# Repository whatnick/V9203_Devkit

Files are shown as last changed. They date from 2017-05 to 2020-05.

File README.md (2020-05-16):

# V9203 FeatherWing Devkit
An evaluation board for Vangotech V9203 3-phase energy monitor in a
Featherwing format. It has been tested with Arduino enabled feathers
and should work with any Arduino platform with an SPI bus.

The SPI bus is 3.3v and exposed via the Feather headers and the JST
connector on the top for people wishing to use it with non-feather
format boards as host processor.

The board can be obtained on:

- [Tindie](https://www.tindie.com/products/whatnick/v9203-featherwing/)
- [OSHPark](https://oshpark.com/shared_projects/62lfzmN7)
- [Aisler](https://aisler.net/p/OBAOETDS)
- [PCBWay](https://www.pcbway.com/project/shareproject/V9203_Devkit_Featherwing.html)
  
## Board Images

### Rendered

**Top Render**

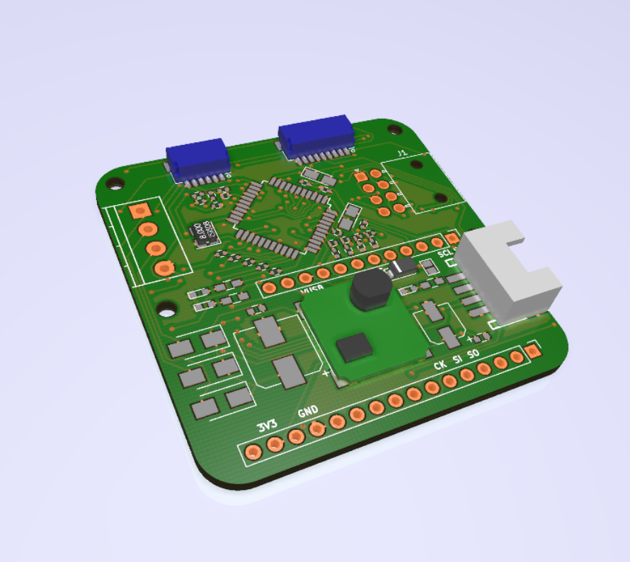
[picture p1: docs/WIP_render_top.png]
Top Render


**Bottom Render**

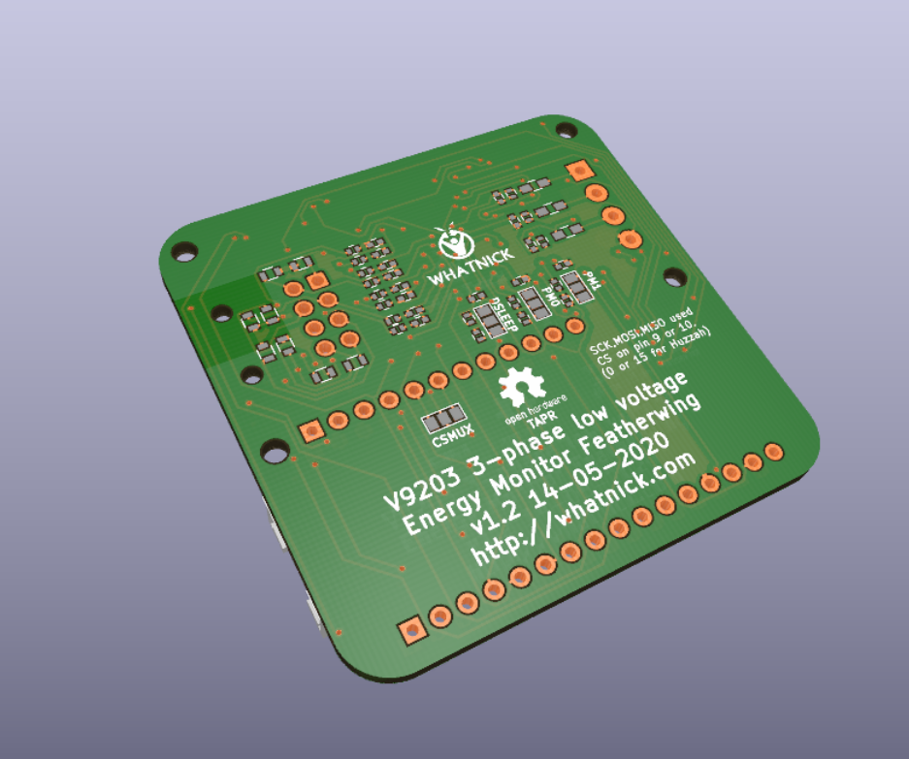
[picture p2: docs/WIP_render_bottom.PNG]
Bottom Render


### Assembled (with RJ45)

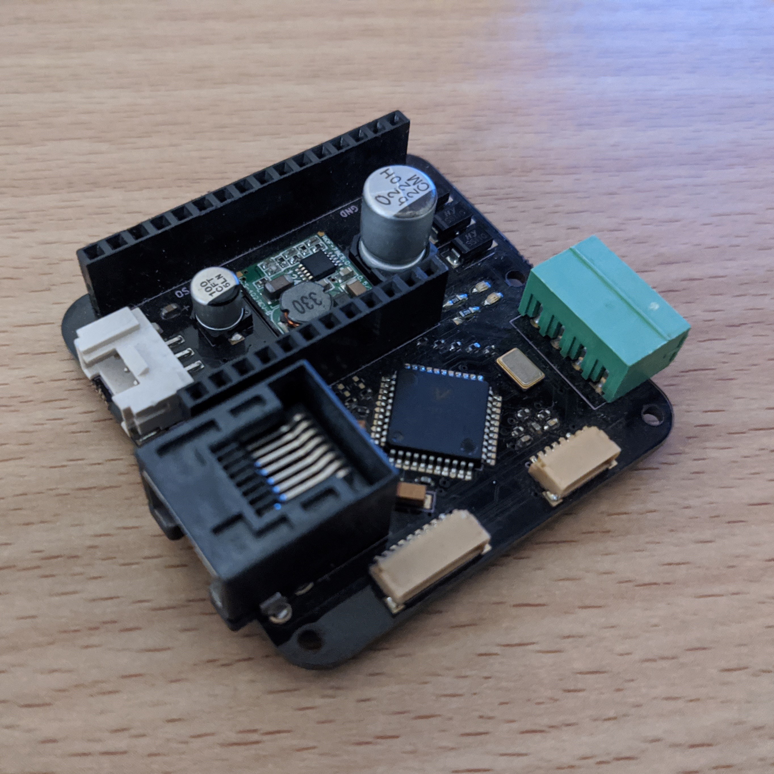
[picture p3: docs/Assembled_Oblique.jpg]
Assembled Oblique


## Arduino Firmware
Arduino Firmware if available in [GitHub](https://github.com/whatnick/V9203_Arduino).

## Micropython Firmware
WIP

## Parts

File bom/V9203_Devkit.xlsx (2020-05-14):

References | manf# | Value | Footprint | Quantity
C23, C24, C25, C26 | 04025C102KAT2A | 1n | C_0402 | 4
C16, C20, C27 | 04026D105KAT2A | 1u | C_0402 | 3
C22 | 0402YC103KAT2A | 10n | C_0402 | 1
C3 | 0603YD105KAT2A | 1u/16V | C_0603 | 1
C5, C6, C7, C8, C9, C10, C11, C12, C15, C17, C18, C19, C21, C28, C29, C30 | C0402C104K4PAC | 100n | C_0402 | 16
C2 | EEEFT1C101AR | 100u/16V | CP_Elec_5x5.8 | 1
C13, C14 | T491A106K016AT | 10u | CP_Tantalum_Case-A_EIA-3216-18_Reflow | 2
C1 | UCM1H221MNL1GS | 220u/50V | CP_Elec_8x10 | 1
C4 | UMK107BJ105KA-T | 1u/50V | C_0603 | 1
R26 | CPF0402B43KE | 43K | R_0402 | 1
R25 | CPF0402B75KE1 | 75K | R_0402 | 1
R6 | CR0402-FX-1000GLF | 100R | R_0402 | 1
R42, R43, R44 | CRCW0402100KFKED | 100K | R_0402 | 3
R33 | CRCW040210K0FKED | 10K | R_0402 | 1
R29, R30, R31, R32 | CRCW04021K00FKED | 1K | R_0402 | 4
R34, R35, R36, R37, R38, R39, R40, R41 | CRCW040220K0FKED | 20K | R_0402 | 8
R1, R27, R28 | CRG0603F1K0 | 1K | R_0603_HandSoldering | 3
R17, R18, R19, R20, R21, R22, R23, R24 | ERJ3BQF2R4V | 2.4R/10ppm | R_0603 | 8
R10, R11, R12 | RG1608P-104-B | 100K | R_0603_HandSoldering | 3
R2, R3, R4, R5, R7, R8, R9, R13, R14, R15, R16 | RT0402FRE07100RL | 100R | R_0402 | 11
D4, D6, D7 | LTST-C190KRKT | LED | LED_0603 | 3
D5 | PMEG2010ER | D_Schottky | D_SOD-123 | 1
D1, D2, D3 | SS110 | D_Schottky | D_SMA_Standard | 3
U2 | ROF-78E5.0-0.5SMD | ROF-78E | SMD-4 | 1
U1 | V9203 | V9203 | TQFP-44_10x10mm_Pitch0.8mm | 1
Y1 | FA-238V 13.0000MB-K0 | Crystal_GND24 | Crystal_SMD_Abracon_ABM8G-4pin_3.2x2.5mm | 1
J1 | 105314-1108 | Conn_01x08 | Molex_Nano-Fit_105314-xx08_2x04_P2.50mm_Horizontal | 1
J4 | 691322110004 | Screw_Terminal_1x04 | TerminalBlock_Pheonix_PT-3.5mm_4pol | 1
J9 | SM06B-SRSS-TB(LF)(SN) | JST6 | JST_SH_SM06B-SRSS-TB_06x1.00mm_Angled | 1
J6 | SM09B-SRSS-TB(LF)(SN) | JST9 | JST_SH_SM09B-SRSS-TB_09x1.00mm_Angled | 1

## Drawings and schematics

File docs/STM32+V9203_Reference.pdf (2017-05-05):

U2

DF04

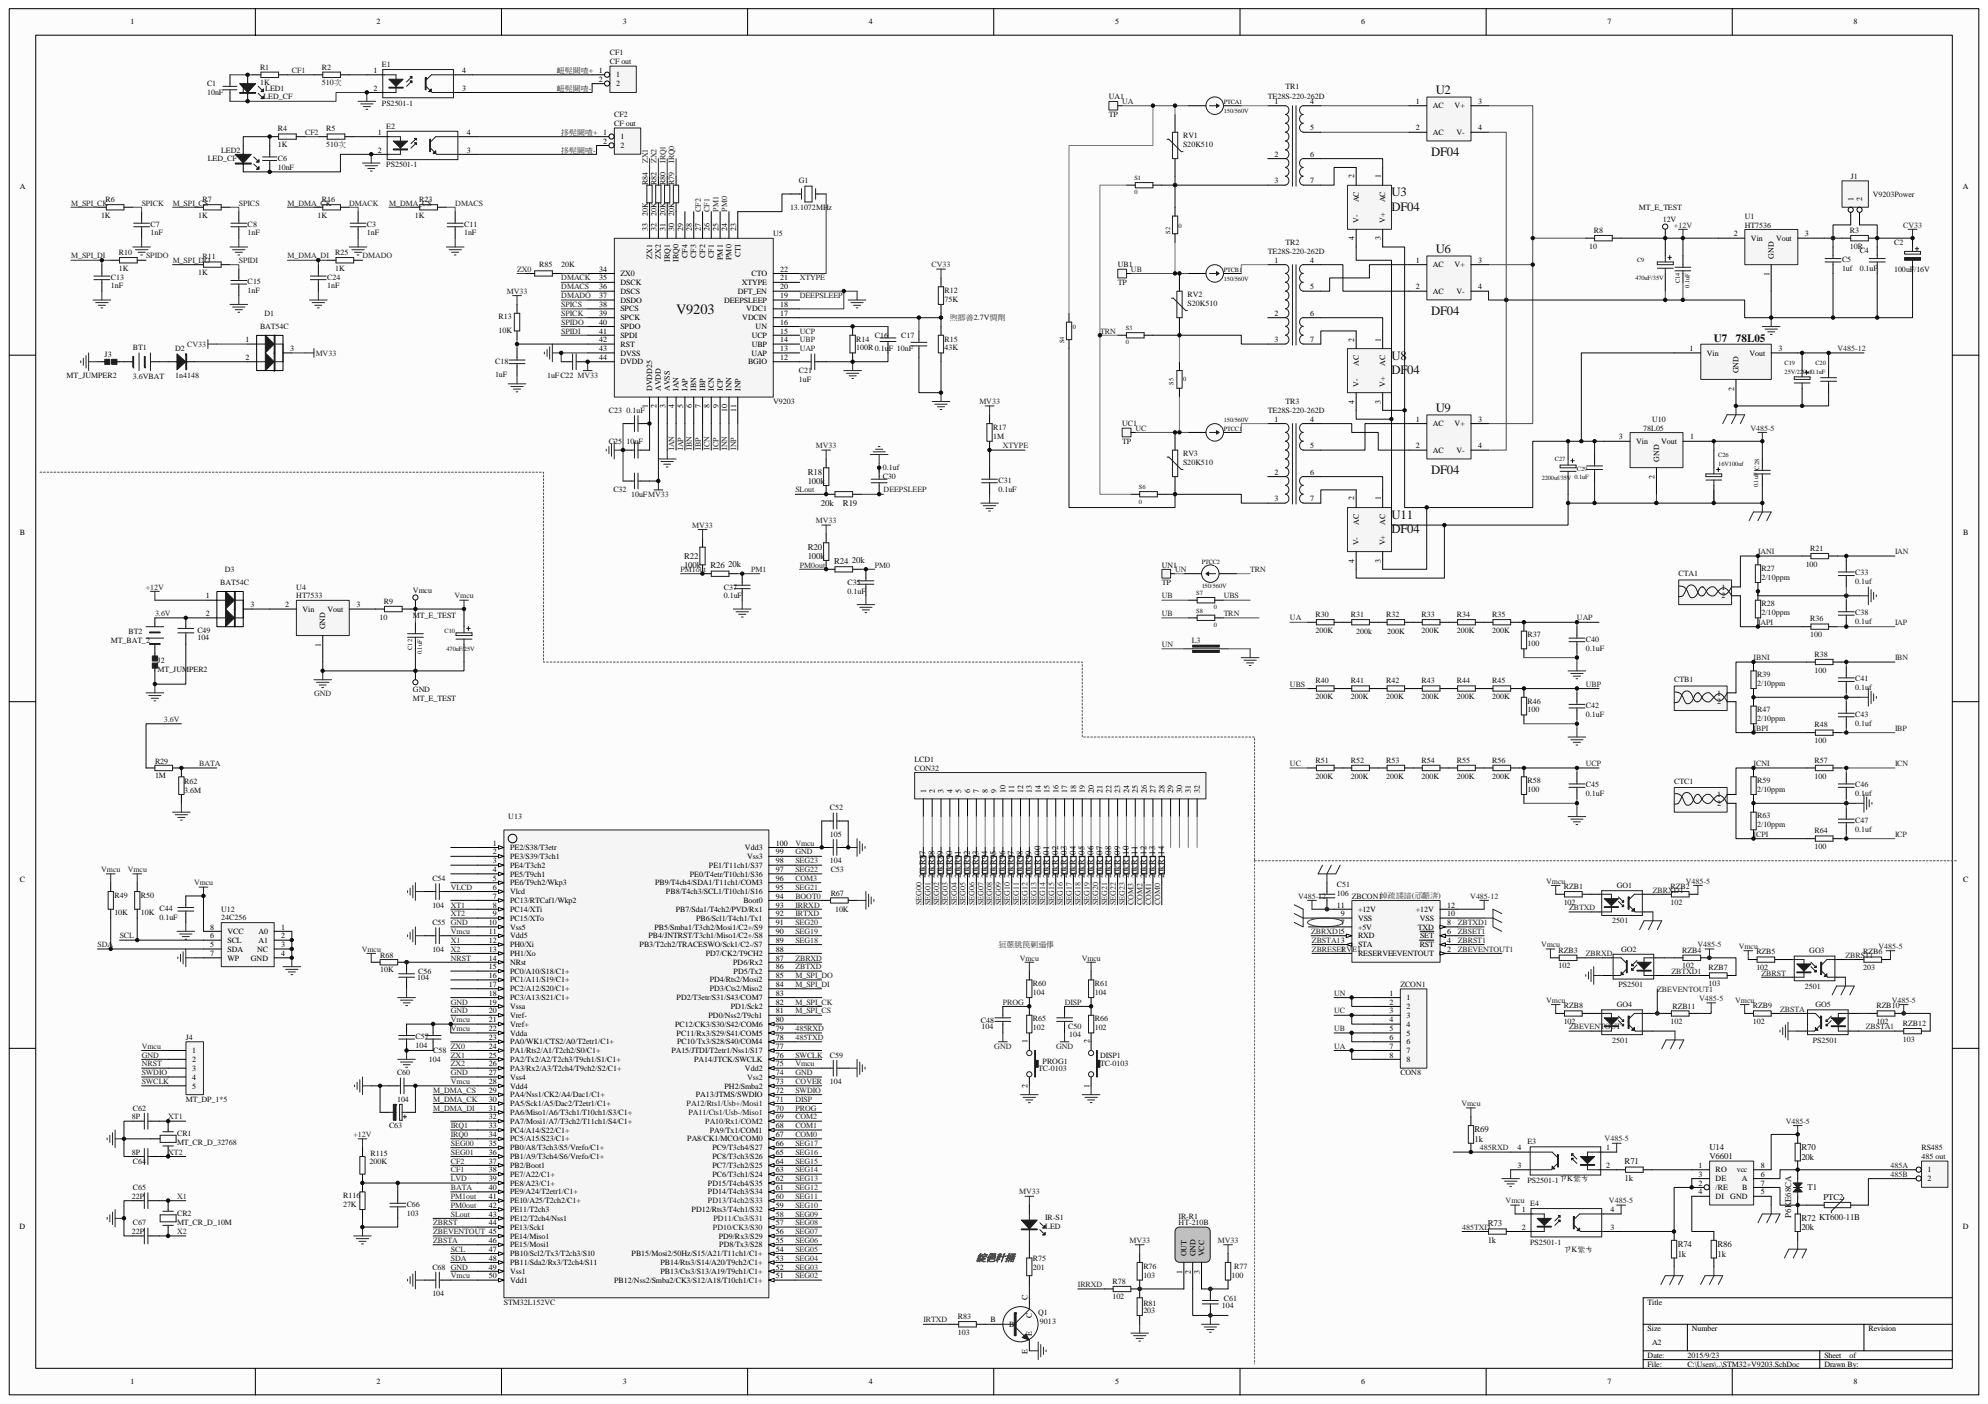
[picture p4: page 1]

Size A2 | Number | Revision

Date: 2015/9/23 | Sheet of
File: C:\Users\..\STM32+V9203.SchDoc | Drawn By:

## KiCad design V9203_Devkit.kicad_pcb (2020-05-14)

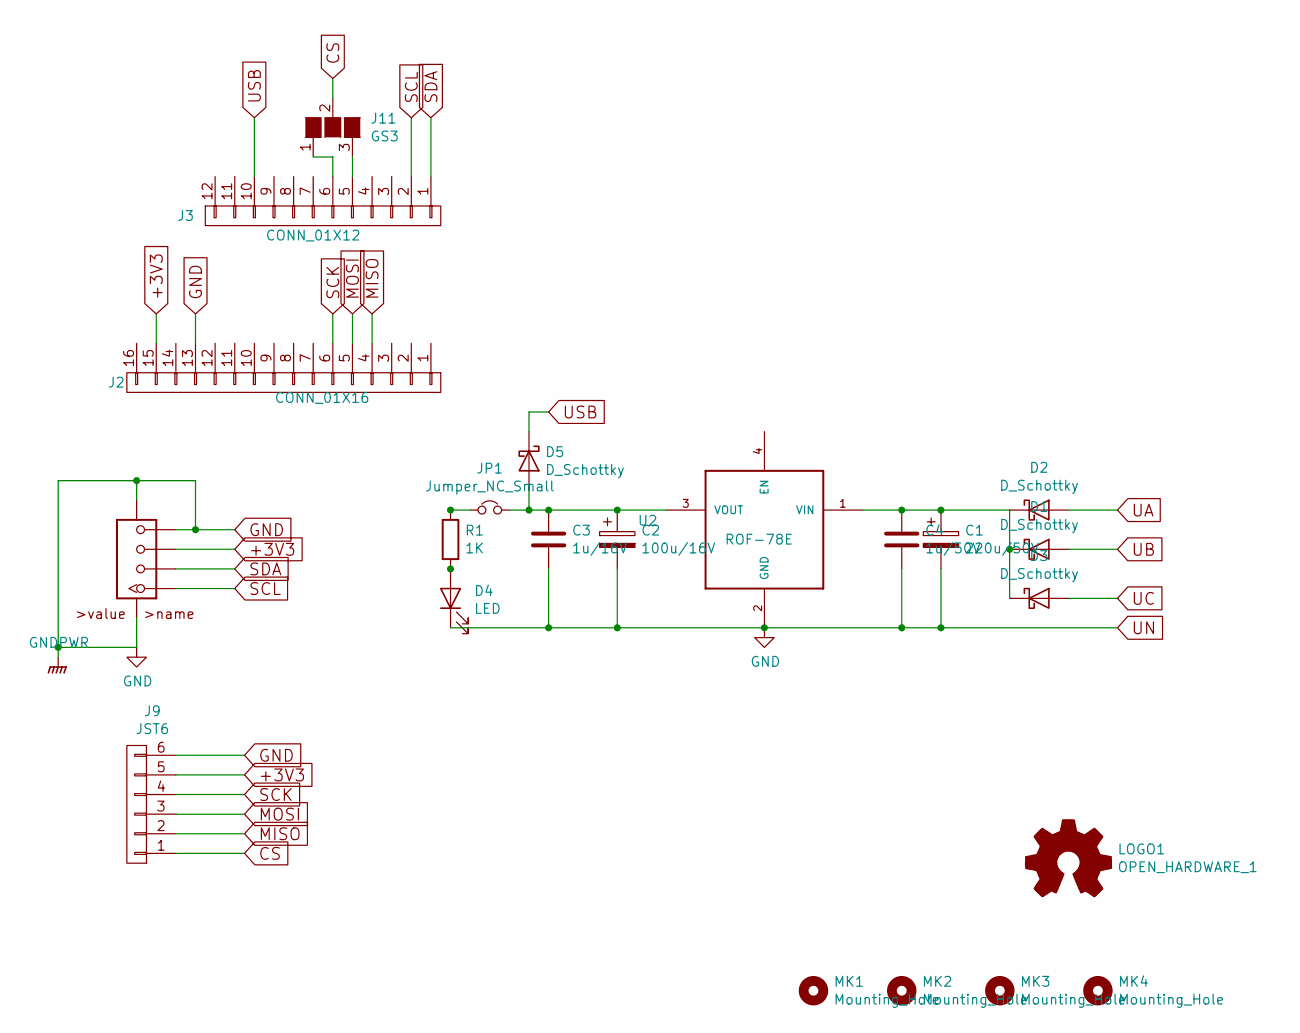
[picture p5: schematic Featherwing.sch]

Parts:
C1: 220u/50V; CP_Elec_8x10
C2: 100u/16V; CP_Elec_5x5.8
C3: 1u/16V; C_0603
C4: 1u/50V; C_0603
D1, D2, D3: D_Schottky; D_SMA_Standard
D4: LED; LED_0603
D5: D_Schottky; D_SOD-123
J2: CONN_01X16; Socket_Strip_Straight_1x16_Pitch2.54mm
J3: CONN_01X12; Socket_Strip_Straight_1x12_Pitch2.54mm
J5: GROVE-CONNECTOR-SMD-90D(4+2P-2.0); HW4-SMD-2.0-90D
J9: JST6; JST_SH_SM06B-SRSS-TB_06x1.00mm_Angled
J11: GS3
JP1: Jumper_NC_Small; GS2
LOGO1: OPEN_HARDWARE_1; OSHW-Logo2_7.3x6mm_SilkScreen
MK1, MK2, MK3, MK4: Mounting_Hole; MountingHole_2.2mm_M2
R1: 1K; R_0603_HandSoldering
U2: ROF-78E; SMD-4

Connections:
+3V3: J2.15, J5.3, J9.5; also elsewhere on the board
CS: J9.1, J11.2 (G2); also elsewhere on the board
GND: C1.2, C2.2, C3.2, C4.2, D4.1 (K), J2.13, J5.4, J5.SS1, J5.SS2, J9.6, U2.2 (GND); also elsewhere on the board
MISO: J2.4, J9.2; also elsewhere on the board
MOSI: J2.5, J9.3; also elsewhere on the board
unnamed: C1.1, C4.1, D1.1 (K), D2.1 (K), D3.1 (K), U2.1 (VIN)
unnamed: C2.1, C3.1, D5.2 (A), JP1.2, U2.3 (VOUT)
unnamed: D4.2 (A), R1.2
unnamed: J3.6, J11.1 (G1)
unnamed: J3.5, J11.3 (G3)
unnamed: JP1.1, R1.1
SCK: J2.6, J9.4; also elsewhere on the board
SCL: J3.2, J5.1
SDA: J3.1, J5.2
UA: D2.2 (A); also elsewhere on the board
UB: D1.2 (A); also elsewhere on the board
UC: D3.2 (A); also elsewhere on the board
USB: D5.1 (K), J3.10

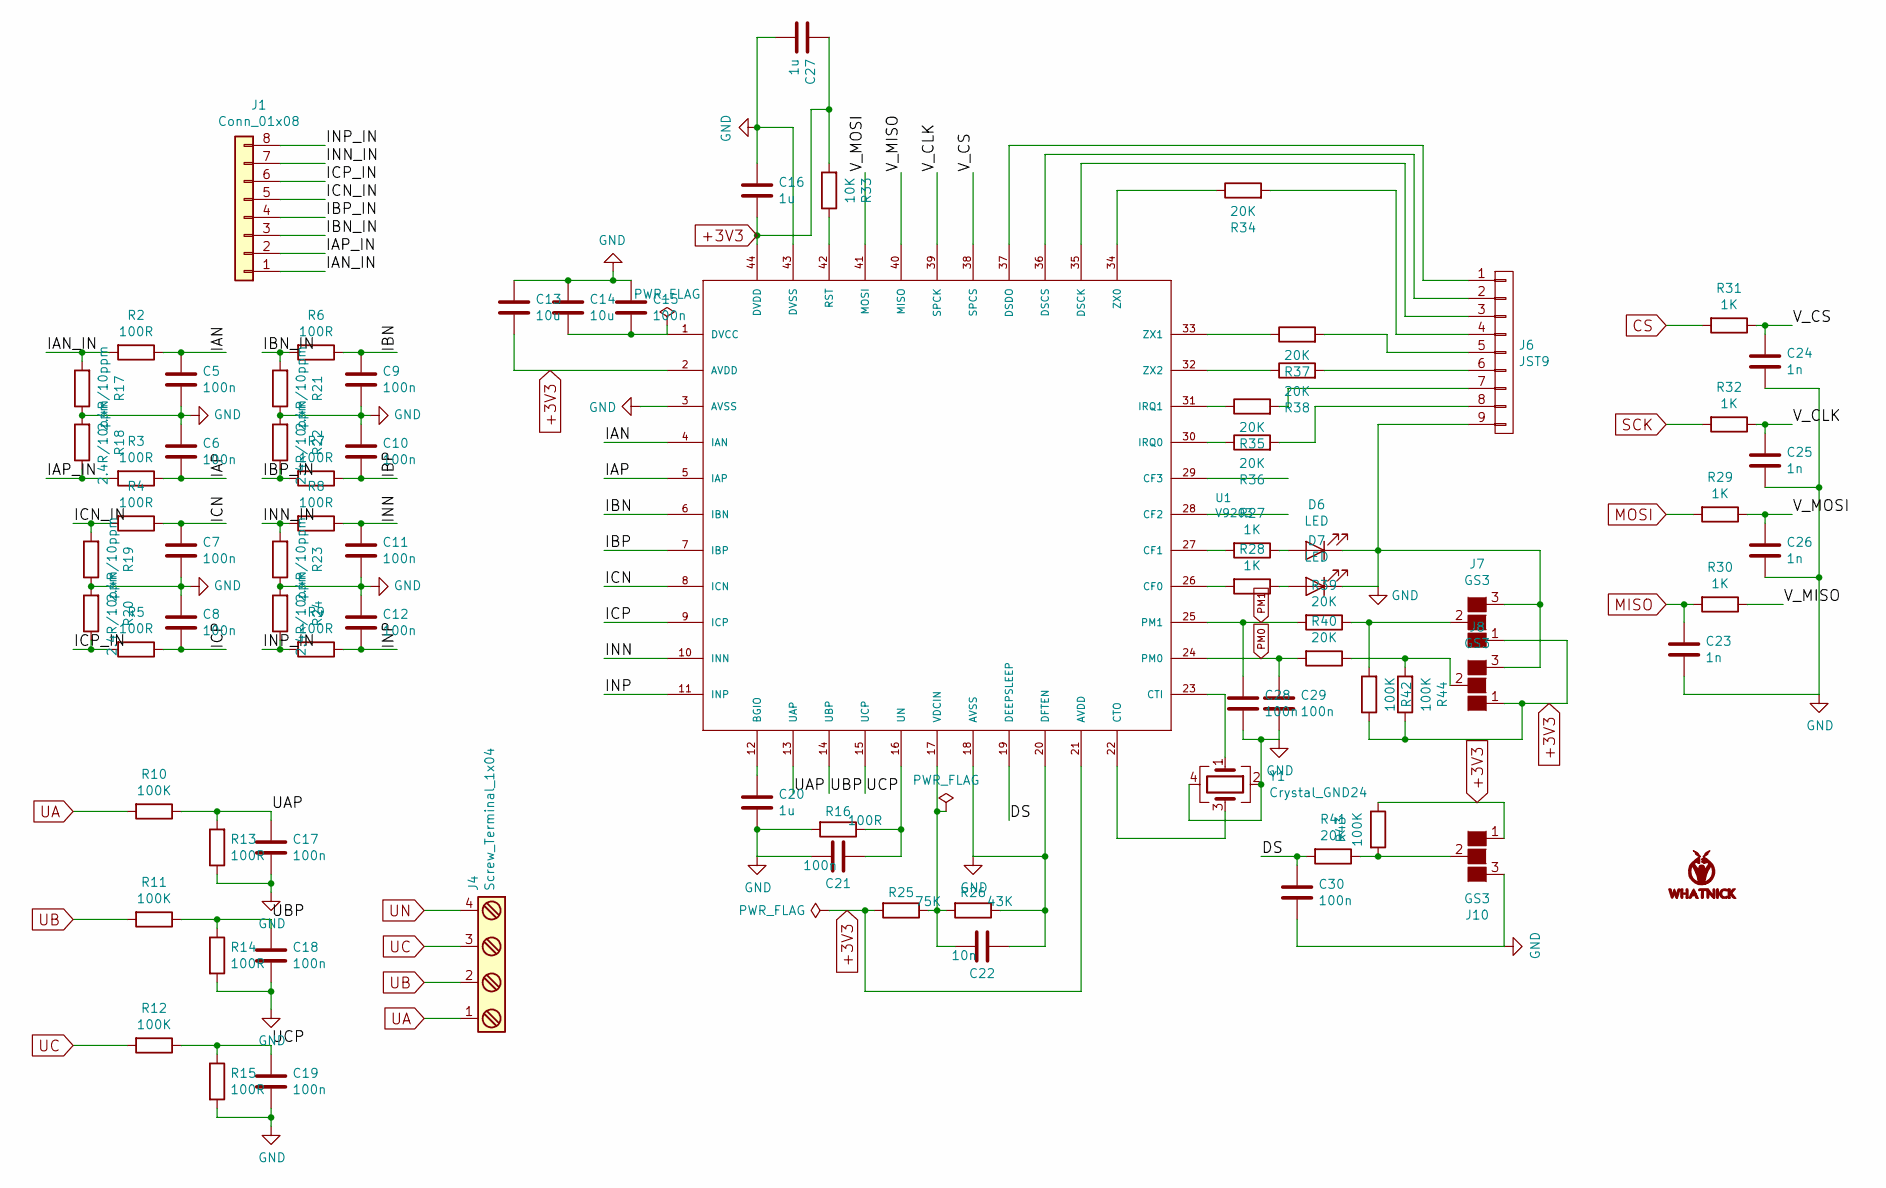
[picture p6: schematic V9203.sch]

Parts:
C5, C6, C7, C8, C9, C10, C11, C12, C15, C17, C18, C19, C21, C28, C29, C30: 100n; C_0402
C13, C14: 10u; CP_Tantalum_Case-A_EIA-3216-18_Reflow
C16, C20, C27: 1u; C_0402
C22: 10n; C_0402
C23, C24, C25, C26: 1n; C_0402
D6, D7: LED; LED_0603
J1: Conn_01x08; Molex_Nano-Fit_105314-xx08_2x04_P2.50mm_Horizontal
J4: Screw_Terminal_1x04; TerminalBlock_Pheonix_PT-3.5mm_4pol
J6: JST9; JST_SH_SM09B-SRSS-TB_09x1.00mm_Angled
J7, J8, J10: GS3
LOGO2: LOGO; Whatnick_logo
R2, R3, R4, R5, R6, R7, R8, R9, R13, R14, R15, R16: 100R; R_0402
R10, R11, R12: 100K; R_0603_HandSoldering
R17, R18, R19, R20, R21, R22, R23, R24: 2.4R/10ppm; R_0603
R25: 75K; R_0402
R26: 43K; R_0402
R27, R28: 1K; R_0603_HandSoldering
R29, R30, R31, R32: 1K; R_0402
R33: 10K; R_0402
R34, R35, R36, R37, R38, R39, R40, R41: 20K; R_0402
R42, R43, R44: 100K; R_0402
U1: V9203; TQFP-44_10x10mm_Pitch0.8mm
Y1: Crystal_GND24; Crystal_SMD_Abracon_ABM8G-4pin_3.2x2.5mm

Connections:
+3V3: C13.2, C16.1, C27.2, J7.1 (G1), J8.1 (G1), J10.1 (G1), R25.2, R33.2, R42.1, R43.1, R44.1, U1.2 (AVDD), U1.21 (AVDD), U1.44 (DVDD); also elsewhere on the board
/V9203/DS: C30.1, R41.2, U1.19 (DEEPSLEEP)
/V9203/IAN: C5.1, R2.1, U1.4 (IAN)
/V9203/IAN_IN: J1.1, R2.2, R17.2
/V9203/IAP: C6.2, R3.1, U1.5 (IAP)
/V9203/IAP_IN: J1.2, R3.2, R18.1
/V9203/IBN: C9.1, R6.1, U1.6 (IBN)
/V9203/IBN_IN: J1.3, R6.2, R21.2
/V9203/IBP: C10.2, R7.1, U1.7 (IBP)
/V9203/IBP_IN: J1.4, R7.2, R22.1
/V9203/ICN: C7.1, R4.1, U1.8 (ICN)
/V9203/ICN_IN: J1.5, R4.2, R19.2
/V9203/ICP: C8.2, R5.1, U1.9 (ICP)
/V9203/ICP_IN: J1.6, R5.2, R20.1
/V9203/INN: C11.1, R8.1, U1.10 (INN)
/V9203/INN_IN: J1.7, R8.2, R23.2
/V9203/INP: C12.2, R9.1, U1.11 (INP)
/V9203/INP_IN: J1.8, R9.2, R24.1
/V9203/UAP: C17.1, R10.1, R13.2, U1.13 (UAP)
/V9203/UBP: C18.1, R11.1, R14.1, U1.14 (UBP)
/V9203/UCP: C19.1, R12.1, R15.1, U1.15 (UCP)
/V9203/V_CLK: C25.1, R32.1, U1.39 (SPCK)
/V9203/V_CS: C24.1, R31.1, U1.38 (SPCS)
/V9203/V_MISO: R30.1, U1.40 (MISO)
/V9203/V_MOSI: C26.1, R29.1, U1.41 (MOSI)
CS: R31.2; also elsewhere on the board
GND: C5.2, C6.1, C7.2, C8.1, C9.2, C10.1, C11.2, C12.1, C13.1, C14.1, C15.1, C16.2, C17.2, C18.2, C19.2, C20.1, C21.2, C22.1, C23.2, C24.2, C25.2, C26.2, C27.1, C28.2, C29.2, C30.2, D6.1 (K), D7.1 (K), J4.4, J6.9, J7.3 (G3), J8.3 (G3), J10.3 (G3), R13.1, R14.2, R15.2, R16.2, R17.1, R18.2, R19.1, R20.2, R21.1, R22.2, R23.1, R24.2, R26.1, U1.3 (AVSS), U1.18 (AVSS), U1.20 (DFTEN), U1.43 (DVSS), Y1.2, Y1.4; also elsewhere on the board
MISO: C23.1, R30.2; also elsewhere on the board
MOSI: R29.2; also elsewhere on the board
unnamed: C14.2, C15.2, U1.1 (DVCC)
unnamed: C20.2, U1.12 (BGIO)
unnamed: C21.1, R16.1, U1.16 (UN)
unnamed: C22.2, R25.1, R26.2, U1.17 (VDCIN)
unnamed: D6.2 (A), R27.1
unnamed: D7.2 (A), R28.1
unnamed: J6.1, U1.37 (DSDO)
unnamed: J6.2, U1.36 (DSCS)
unnamed: J6.3, U1.35 (DSCK)
unnamed: J6.4, R34.2
unnamed: J6.5, R37.2
unnamed: J6.6, R38.2
unnamed: J6.7, R35.2
unnamed: J6.8, R36.2
unnamed: J7.2 (G2), R39.1, R42.2
unnamed: J8.2 (G2), R40.1, R44.2
unnamed: J10.2 (G2), R41.1, R43.2
unnamed: R27.2, U1.27 (CF1)
unnamed: R28.2, U1.26 (CF0)
unnamed: R33.1, U1.42 (RST)
unnamed: R34.1, U1.34 (ZX0)
unnamed: R35.1, U1.31 (IRQ1)
unnamed: R36.1, U1.30 (IRQ0)
unnamed: R37.1, U1.33 (ZX1)
unnamed: R38.1, U1.32 (ZX2)
unnamed: U1.22 (CTO), Y1.3
unnamed: U1.23 (CTI), Y1.1
PM0: C29.1, R40.2, U1.24 (PM0)
PM1: C28.1, R39.2, U1.25 (PM1)
SCK: R32.2; also elsewhere on the board
UA: J4.1, R10.2; also elsewhere on the board
UB: J4.2, R11.2; also elsewhere on the board
UC: J4.3, R12.2; also elsewhere on the board

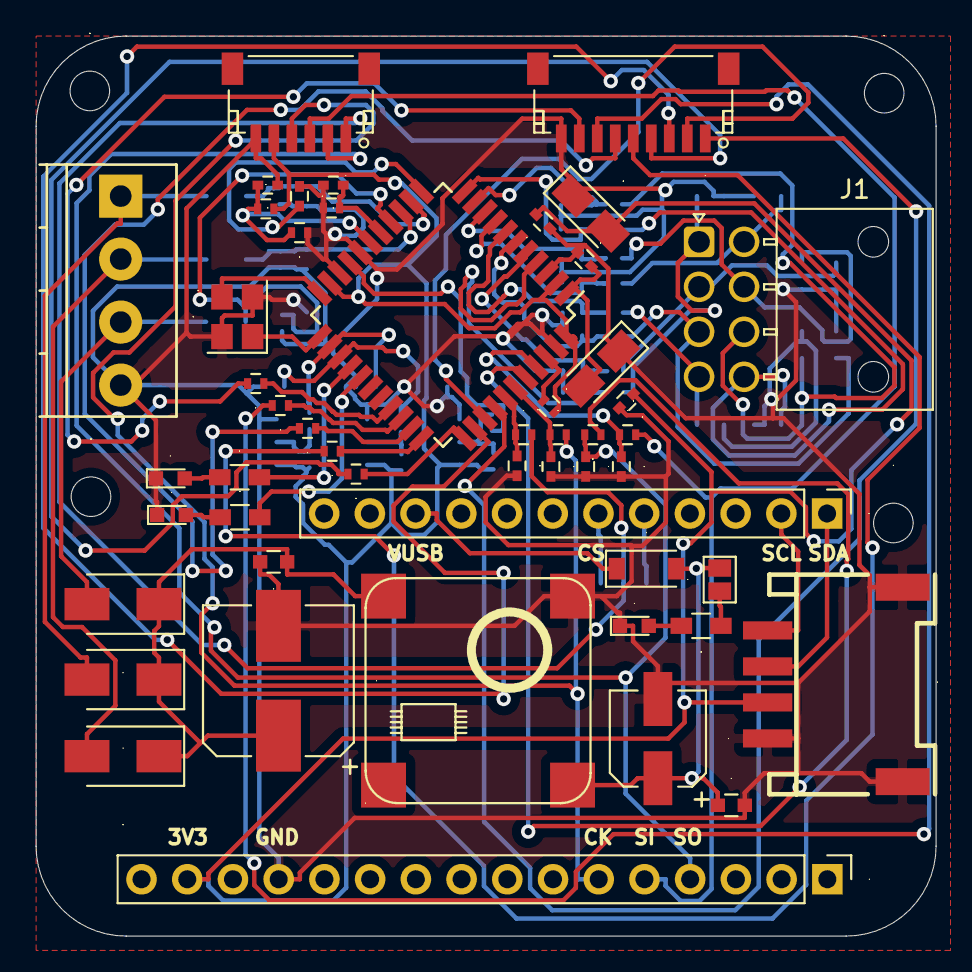
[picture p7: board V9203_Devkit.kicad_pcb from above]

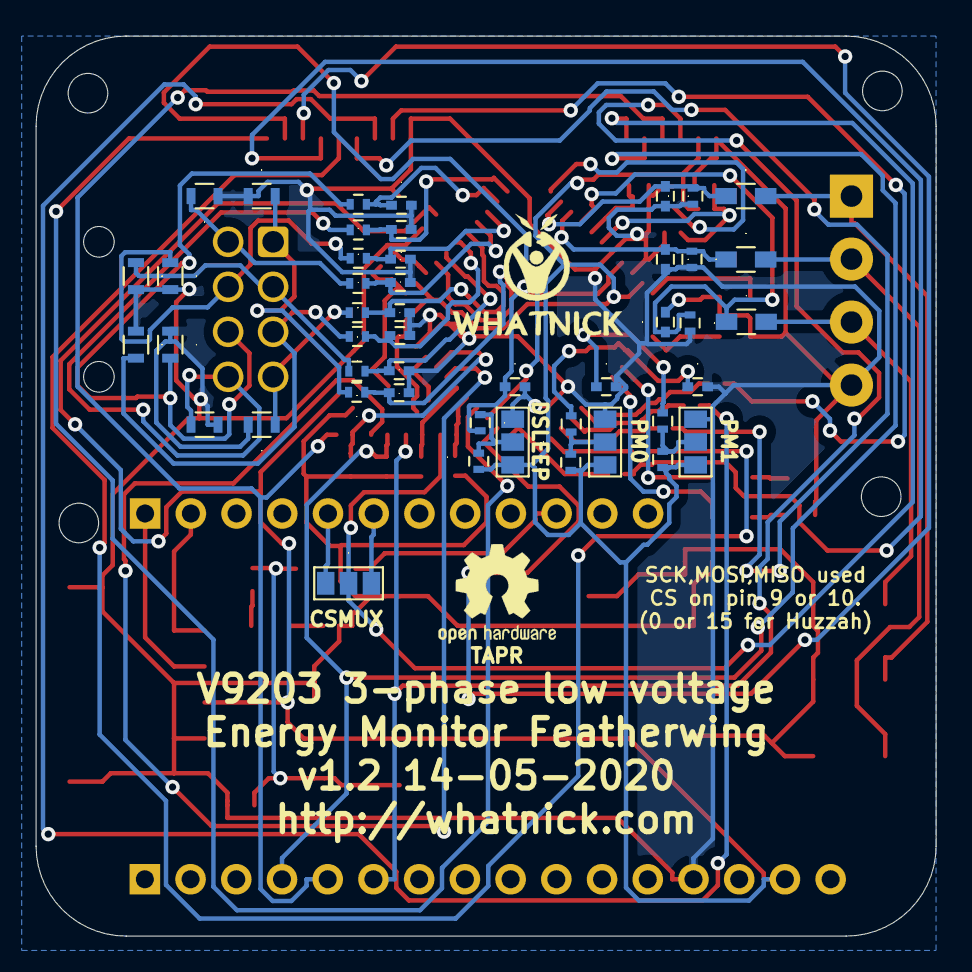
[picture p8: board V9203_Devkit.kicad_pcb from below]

Board: 2 copper layers, 50.0 x 50.0 mm, 102 parts (48 on the bottom side), 71 nets.

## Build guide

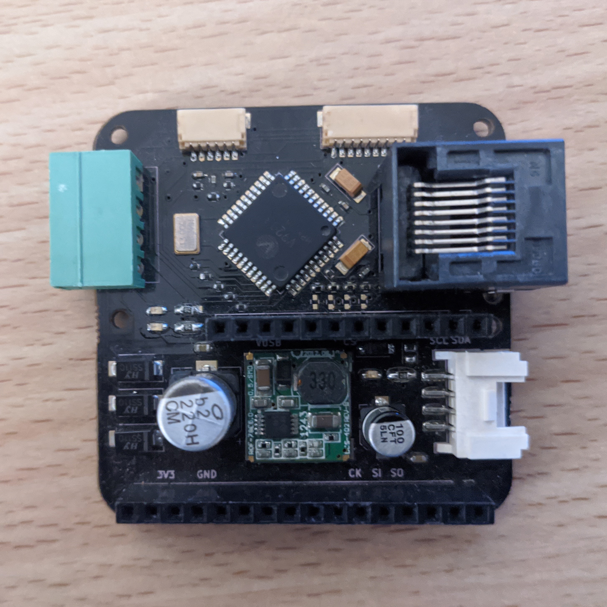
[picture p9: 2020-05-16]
docs/Assembled_Top.jpg

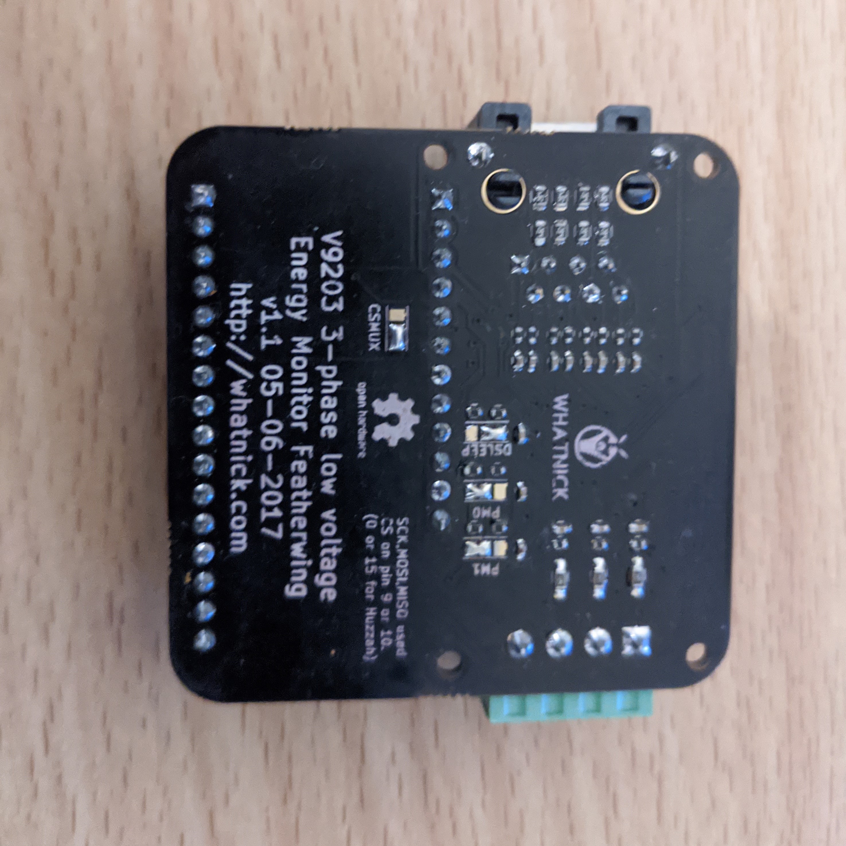
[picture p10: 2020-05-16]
docs/Assembled_Bottom.jpg

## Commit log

2017-04-04 Initial import
    [Featherwing.sch, V9203.sch, V9203_Devkit.kicad_pcb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]
2017-04-17 Added more parts to featherwing
    [Featherwing.sch, V9203.sch, V9203_Devkit.kicad_pcb]
2017-04-23 Laid out most parts within PCB bounds
    [Featherwing.sch, V9203.sch, V9203_Devkit.kicad_pcb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]
2017-04-24 Neaten up parts layout
    [V9203.sch, V9203_Devkit.kicad_pcb]
2017-04-25 Added JST footprints, mounting holes and logos
    [Featherwing.sch, V9203.sch, V9203_Devkit.kicad_pcb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]
2017-04-25 Blanked all test
    [V9203_Devkit.kicad_pcb]
2017-04-25 Blanked all text
    [Featherwing.sch]
2017-04-25 Added more signals to JST connector including DMA
    [V9203.sch, V9203_Devkit.kicad_pcb]
2017-04-26 Flipped connectors
    [V9203_Devkit.kicad_pcb]
2017-04-28 More connector models
2017-04-29 Added PM0,1 and Deepsleep circuits
    [Featherwing.sch, V9203.sch, V9203_Devkit.kicad_pcb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]
2017-04-30 Laid out components so far pending ERC,routing and review
    [Featherwing.sch, V9203.sch, V9203_Devkit.kicad_pcb]
2017-04-30 Ran ERC and updated pcb
    [Featherwing.sch, V9203.sch, V9203_Devkit.kicad_pcb]
2017-04-30 Set up for Freeroute
    [V9203_Devkit.kicad_pcb]
2017-05-01 Freeroute run
    [V9203_Devkit.kicad_pcb]
2017-05-01 Changed crystal and diode models
    [V9203_Devkit.kicad_pcb]
2017-05-02 With CS mux, improve silk screen in next rev
    [Featherwing.sch, V9203_Devkit.kicad_pcb]
2017-05-02 Added ground plane
    [V9203_Devkit.kicad_pcb]
2017-05-02 Added silk screen markers
    [Featherwing.sch, V9203.sch, V9203_Devkit.kicad_pcb]
2017-05-02 Added silk screen for pins
    [V9203_Devkit.kicad_pcb]
2017-05-05 Added component values from reference design
    [Featherwing.sch, V9203.sch, V9203_Devkit.kicad_pcb]
2017-05-06 Started adding part numbers
    [Featherwing.sch, V9203.sch]
2017-05-07 Added more part numbers
    [Featherwing.sch, V9203.sch]
2017-05-08 More part numbers
    [V9203.sch]
2017-05-09 JST parts
    [Featherwing.sch, V9203.sch]
2017-06-04 Fixed a ground connection
    [V9203.sch, V9203_Devkit.kicad_pcb]
2017-06-05 Bump version
    [V9203_Devkit.kicad_pcb]
2020-05-01 Migrate to kicad 5
    [Featherwing-2020-05-01-20-57-36.sch, V9203-2020-05-01-20-57-36.sch, V9203_Devkit-2020-05-01-20-57-36.sch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]
2020-05-07 Link to Arduino Firmware
2020-05-10 Add iBOM
    [Featherwing.sch, V9203.sch]
2020-05-14 New data and gerbers
    [V9203_Devkit-B_Cu.gbl, V9203_Devkit-B_Mask.gbs, V9203_Devkit-B_SilkS.gbo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]
2020-05-14 Add gerber zip to ignore
2020-05-14 Add Bom Excel
    [V9203_Devkit.xlsx]
